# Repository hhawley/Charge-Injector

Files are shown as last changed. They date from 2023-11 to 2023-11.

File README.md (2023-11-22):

# Charge Injector

The amplifier used in my setup could not be calibrated using a sine wave as the gain parameter was a wide-band gain (from few kHz to 200 MHz). Ideally, this gain can be calculated when the amplifier is injected with a pulse with a known total integrated charge. The total charge can be estimated with the next equation

$Q = \Delta V C$

This charge injector (or whatever is the official technical name, I could never find it!) was built with the most accurate capacitor I could buy which is a  9.1 pF, $C$, 0.5% NP0 resistor. This circuit needs a high precision (in voltage) square square to work. I made mine with a 10V precision voltage reference, a 10:1 voltage divider (for a 1Vpp square wave), and a signal relay.

The main contributor to the error budget comes from $C$ and everything else contributed almost nothing.

However, the final design was a "failure". Problems such as not enough filtering of the power rails (which was solved with enough hand-soldered capacitors: see the picture!) and the noise mostly dominated at low frequency  (1-10 kHz) made this design not really suitable for the application.

It was a good project built and tested within 2-3 weeks.

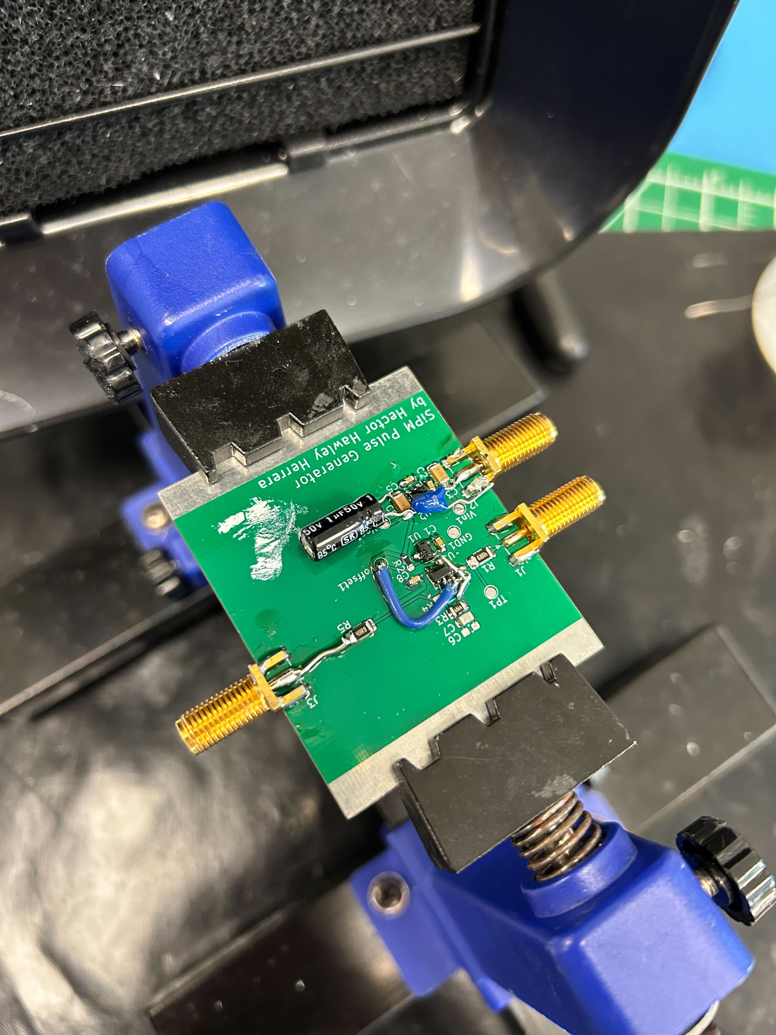
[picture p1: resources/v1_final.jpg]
Final design


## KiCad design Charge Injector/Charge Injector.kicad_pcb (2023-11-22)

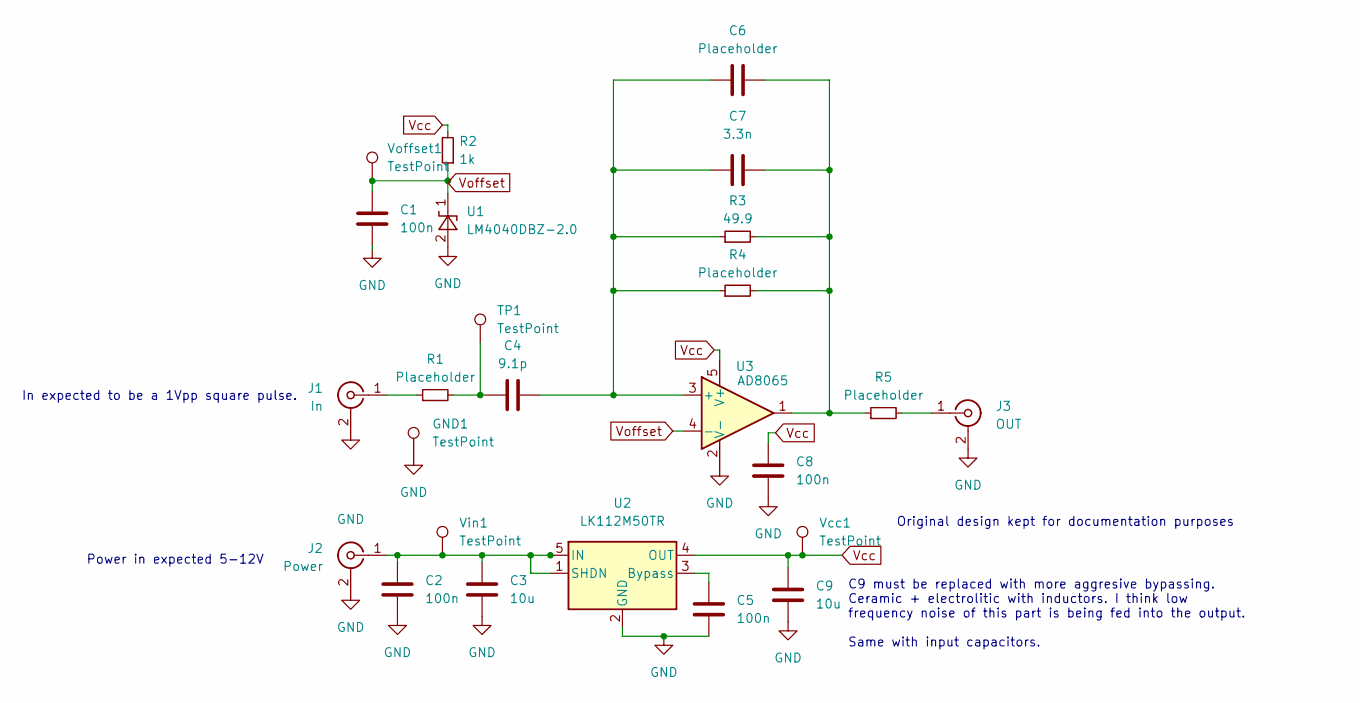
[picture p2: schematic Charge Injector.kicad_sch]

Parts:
C1, C2, C5, C8: 100n; C_0603_1608Metric_Pad1.08x0.95mm_HandSolder
C3, C9: 10u; C_1206_3216Metric_Pad1.33x1.80mm_HandSolder
C4: 9.1p; C_0402_1005Metric_Pad0.74x0.62mm_HandSolder
C6: Placeholder; C_0603_1608Metric_Pad1.08x0.95mm_HandSolder
C7: 3.3n; C_0603_1608Metric_Pad1.08x0.95mm_HandSolder
GND1: TestPoint; TestPoint_Pad_D1.5mm
J1: In; SMA_Samtec_SMA-J-P-X-ST-EM1_EdgeMount
J2: Power; SMA_Samtec_SMA-J-P-X-ST-EM1_EdgeMount
J3: OUT; SMA_Samtec_SMA-J-P-X-ST-EM1_EdgeMount
R1, R4, R5: Placeholder; R_1206_3216Metric_Pad1.30x1.75mm_HandSolder
R2: 1k; R_0603_1608Metric_Pad0.98x0.95mm_HandSolder
R3: 49.9; C_0805_2012Metric_Pad1.18x1.45mm_HandSolder
TP1: TestPoint; TestPoint_Pad_D1.5mm
U1: LM4040DBZ-2.0; SOT-23
U2: LK112M50TR; SOT-23-5
U3: AD8065; SOT-23-5
Vcc1: TestPoint; TestPoint_Pad_D1.5mm
Vin1: TestPoint; TestPoint_Pad_D1.5mm
Voffset1: TestPoint; TestPoint_Pad_D1.5mm

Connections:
GND: C1.2, C2.2, C3.2, C5.2, C8.2, C9.2, GND1.1, J1.2 (Ext), J2.2 (Ext), J3.2 (Ext), U1.2 (A), U2.2 (GND), U3.2 (V-)
unnamed: C4.1, R1.2, TP1.1
unnamed: C6.2, C7.1, R3.2, R4.2, R5.1, U3.1
unnamed: J1.1 (In), R1.1
unnamed: C2.1, C3.1, J2.1 (In), U2.1 (SHDN), U2.5 (IN), Vin1.1
unnamed: J3.1 (In), R5.2
unnamed: C5.1, U2.3 (Bypass)
unnamed: C4.2, C6.1, C7.2, R3.1, R4.1, U3.3 (+)
Vcc: C8.1, C9.1, R2.2, U2.4 (OUT), U3.5 (V+), Vcc1.1
Voffset: C1.1, R2.1, U1.1 (K), U3.4 (-), Voffset1.1

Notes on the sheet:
C9 must be replaced with more aggresive bypassing. Ceramic + electrolitic with inductors. I think low frequency noise of this part is being fed into the output. Same with input capacitors.
Original design kept for documentation purposes
Power in expected 5-12V
In expected to be a 1Vpp square pulse.

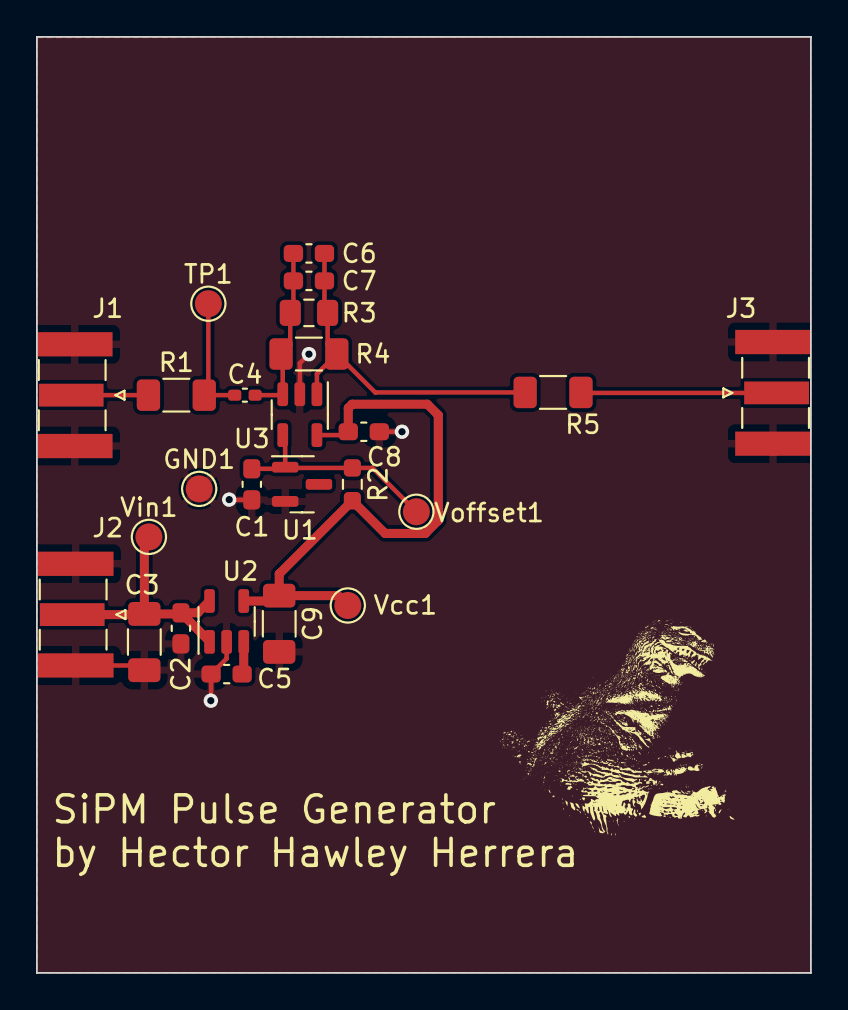
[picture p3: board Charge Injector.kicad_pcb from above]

Board: 2 copper layers, 43.0 x 52.0 mm, 25 parts (0 on the bottom side), 10 nets.
